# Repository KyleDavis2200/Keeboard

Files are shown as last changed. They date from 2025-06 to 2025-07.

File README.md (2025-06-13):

# Keeboard

In this project, I made a custom mechanical keyboard using a Raspberry Pi Pico clone. The main feature that makes this unique is the connectors on either side of the board that allow it to be connected to external modules. I plan to make a wireless macropad / numberpad in a future project, that can be connected to either side of the keyboard to charge. These connectors will also include I²C communication, which should give me the option of adding more features, such as a screen, in the future.



# Features

* Modular design allows for future expansions.
* Tenkeyless Layout
* 87 Keys
* 3D Printed Case and Plate
* 3D Printed TPU Feet
* USB C Connector
* KMK Firmware

# Background

My main inspiration when designing this keyboard came from the Mountain Everest Max. The Everest Max features a removable number pad which can be attached to either side of the keyboard. This allows you to put it on the left side, which is more convenient for daily usage as it allows you to type in numbers with your left hand and move the mouse with your right hand without stretching your hand too far over. This setup is also ideal for gaming as it helps to maximize the mamount of mouse room on the right side of the board. To replicate this functionality in my own board, I put magnetic pogo pins on the sides of the board that allow the macropad/numberpad to connect to the keyboard. The four pins include a 5V pin, a ground pin, and two pins for I²C communication. This should leave me with plenty of options for expandability in the future.

The keyboard itself runs off of a Pi Pico clone, which was chosen for its high quanitity of GPIO pins and USB C port (compared to the Micro USB B port of the actual Pico). It uses MMD Princess V2 Tactile Switches, and its keys are arranged in a 6x17 matrix. The keyboard has a white color scheme with Blue 8008 keycaps. The case and plate are designed to be printed in two halves and then assembled, where they will then be held to gether by keying features, heat set inserts, and the screws running through the case and PCB. The case also features carefully placed cylinders to act like standoffs to support the PCB. The aim with this was to give the board a more solid feel than it otherwise would have, as I was worried about the PCB flexing if a key is pressed too hard.

# Images

### PCB:

Schematic:



Front:



Back:



3D View:



### CAD:

Isometric:



Front View:



Side View:



Top View:



Back View:



# BOM

| Item | Price  | Link |
| --- | --- | --- |
| RP2040 Pico USB C | 1.99 | https://www.aliexpress.us/item/3256808040042288.html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"order"%3A"30"%2C"eval"%3A"1"%7D&pdp_npi=4%40dis%21USD%2110.51%213.69%21%21%2175.16%2126.43%21%40210337c117496162516362210eb7d4%2112000044297086886%21sea%21US%216330817038%21X&curPageLogUid=oRgrVCWBuHse&utparam-url=scene%3Asearch%7Cquery_from%3A |
| Switches x110 | 23.6 | https://www.amazon.com/KPREPUBLIC-Princess-Tactile-Mechanical-Keyboard/dp/B0C533CCXY?th=1 |
| Key Caps | 29.99  | https://www.amazon.com/Sumgsn-Spacebar-Switches-Mechanical-Keyboard/dp/B0BNN2M9QD/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 |
| Stabilizers | 5.54 | https://www.aliexpress.us/item/3256801499984864.html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"order"%3A"111"%2C"eval"%3A"1"%7D&pdp_npi=4%40dis%21USD%215.54%215.54%21%21%215.54%215.54%21%40210318e817496929936517433e29c3%2112000017133740376%21sea%21US%216330817038%21X&curPageLogUid=4ANDMTxK2PfM&utparam-url=scene%3Asearch%7Cquery_from%3A |
| Cable | 2.59 | https://www.amazon.com/FEMORO-Monitor-Display-Transfer-Thunderbolt/dp/B0F23ZT4LV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 |
| PCB | 73.05  | JLC PCB |
| Diodes | 1.39 | idk how to link it since its in dollar express |
| Right Angle Pogo Pins | 6.04 | https://www.aliexpress.us/item/3256807268443322.html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 |
| Schottky Diode | 4.65 | https://www.aliexpress.us/item/3256803563924504.html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 |
| 8x M3 Heat Set Insert | N/A | Already have |
| 4x M3 x 20mm Screw | N/A | Already have |
| 4x M3 x 12mm Screw | N/A | Already have |
| PLA Filament | N/A | Already have |
| TPU Filament | N/A | Already have |
| Total: | 148.84 | |

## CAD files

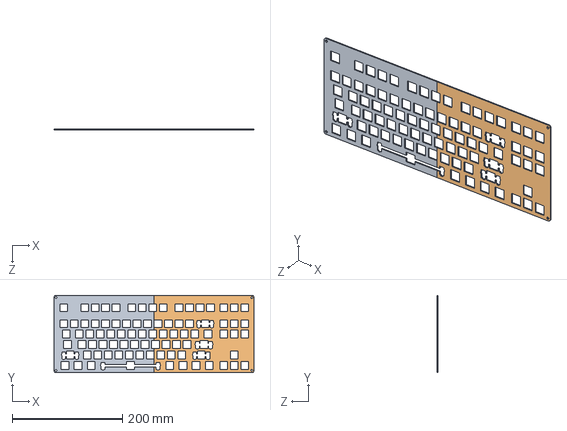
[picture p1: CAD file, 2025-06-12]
Plate STEP.STEP
363.1 x 139.9 x 1.50 mm

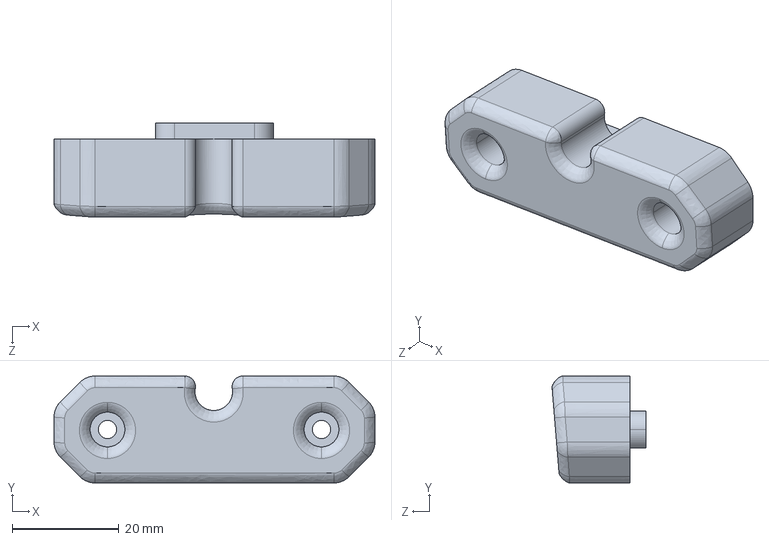
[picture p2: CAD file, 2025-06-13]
CAD/Top Left Foot.STEP
60.0 x 20.0 x 17.6 mm

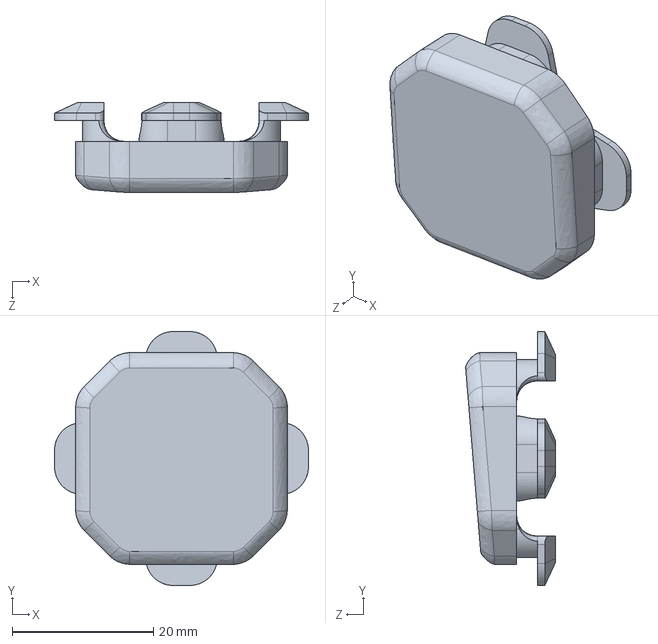
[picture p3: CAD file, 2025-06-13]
CAD/Lower Feet.STEP
36.0 x 36.0 x 12.7 mm

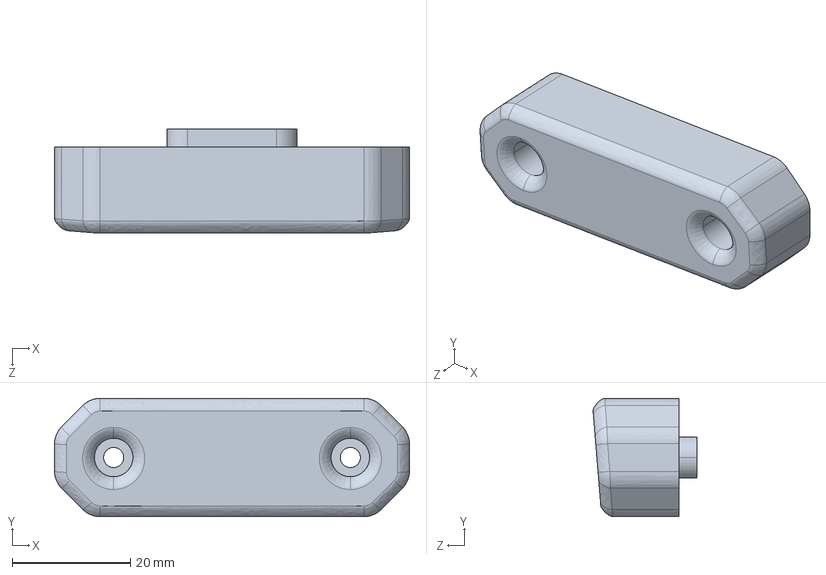
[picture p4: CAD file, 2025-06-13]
CAD/Top Right Foot.STEP
60.0 x 20.0 x 17.6 mm

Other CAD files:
CAD/Case.STEP
CAD/Plate.STEP

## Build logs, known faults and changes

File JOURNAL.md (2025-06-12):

---
title: KeeBoard
author: Kyle Davis
description: A custom keyboard designed with future expandability in mind
created_at: 2025-05-25
---

Total Time: 32 Hours

5/25/2025

4 Hours

I began this project by first researching how keyboard PCBs were laid out, as I knew that would be the main challenge in this project. I came across [a video series by Joe Scotto](https://www.youtube.com/playlist?list=PLBD2IS_t_iWZDMdG_ZF57x9Ebm3kxKqxF) that helped me understand exactly how everything would be laid out. These tutorials guided me towards keyboard-layout-editor.com, where I layed out a standard TKL layout for this keyboard.

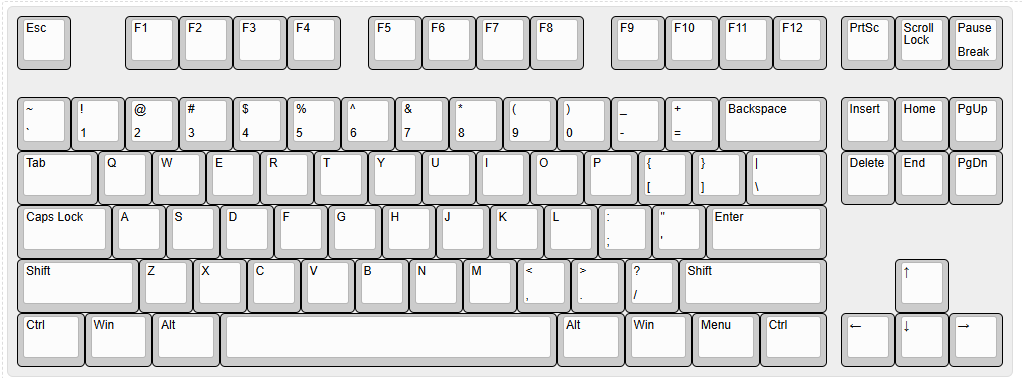
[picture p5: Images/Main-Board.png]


Following the instructions in these tutorials, I then began to plan out how I would layout the columns and rows for this keyboard. 
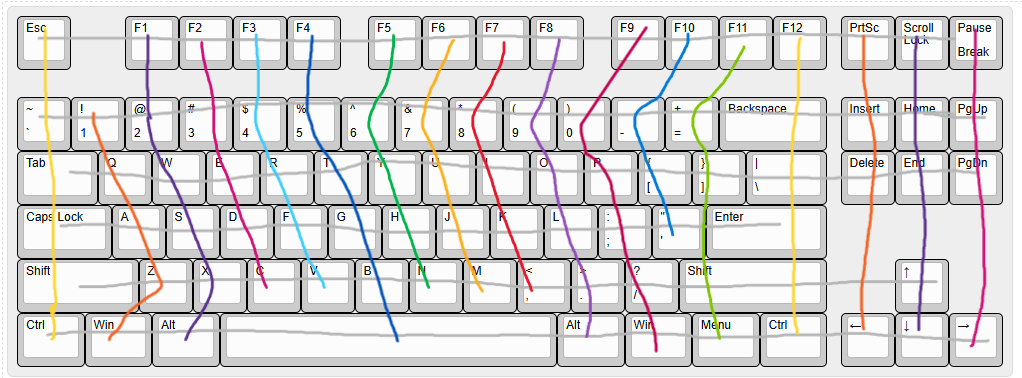
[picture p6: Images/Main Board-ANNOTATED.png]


5/26/2025

8 Hours

Using the previous drawing of the rows and columns for the key matrix, I began making a schematic in KiCad of the keyboard, using symbols from [Joe Scotto's library](https://github.com/joe-scotto/scottokeebs).

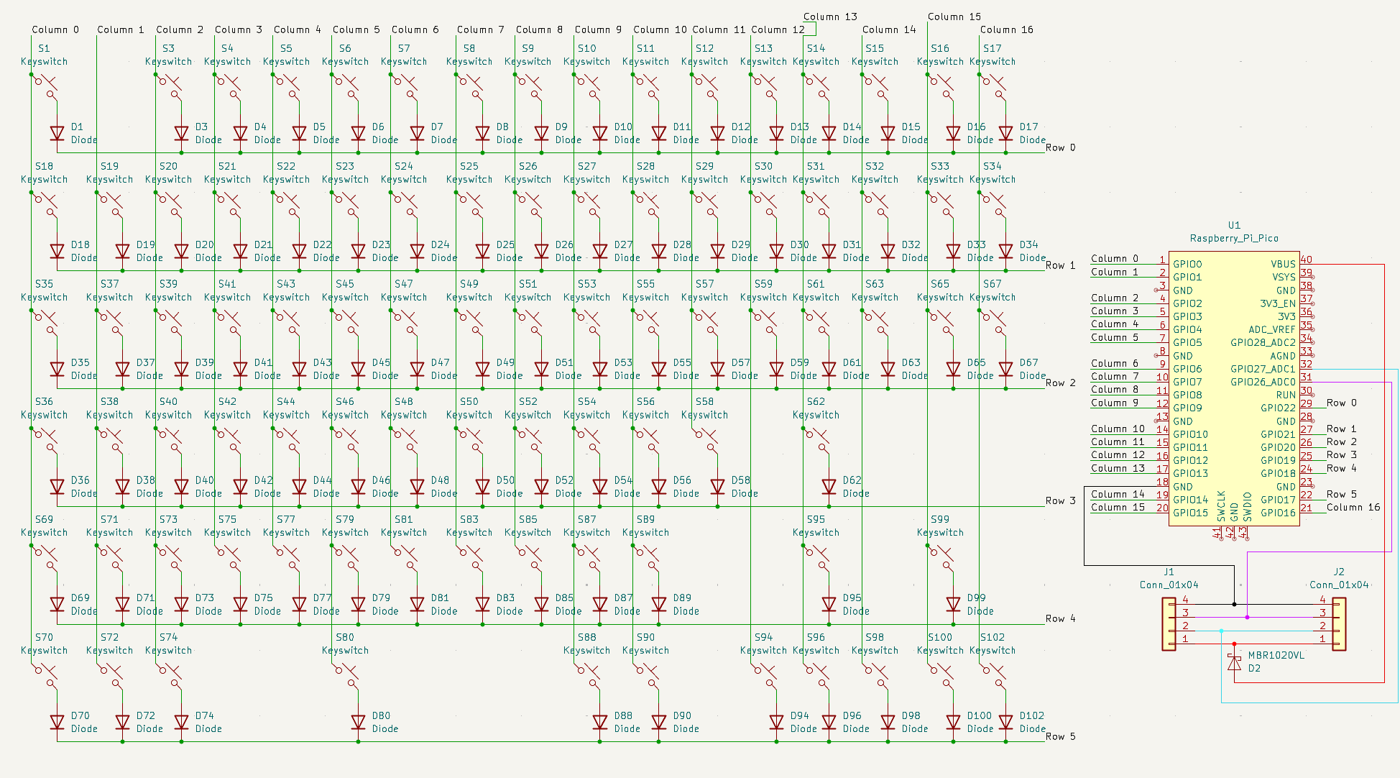
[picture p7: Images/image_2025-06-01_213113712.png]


I then moved onto selecting exactly which switches and keycaps I would use. I opted for Princess Tactile switches and 8008 keycaps. I also selected the cable and stabilizers I would be using for this build at this time.



Next, I created a rough layout of the PCB, including the Pico, the diodes, and all of the key switches.



5/30/25

2 Hours

Today, I polished up the board layout by adjusting the location of the Pico to better fit between the switches and made some of the remaining traces that I had not made previously. At this point, the remaining steps in the PCB design in Kicad are to add the connectors for expanding with future modules, adding a ground plane, and creating mounting for the stabilizers. After that, the rest of the design, designing the case and plate, will be done in Solidworks.

6/1/25

1 Hour

Today, I focused on getting the journal up to date and adding images to the journal. I also went back and switched from 3 pin connectors (which I had only been using 2 pins on, as I could not find 2 pin connectors) for the expandable modules to 4 pin connectors, which allowed me to use I²C to communicate with the external modules. This would allow me to use wired communication to the external modules, instead of just using the connection as a charging port for wireless modules. I do still aim to make a wireless macropad/keypad, but this creates the option of making a screen module or a slider/knob module. As of writing this, I am realizing that the signals for the I²C communication should be sent to seperate GPIO pins from the connector on each side of the keyboard, instead of sharing GPIO pins, which would make it possible to use two modules at a time. After some research, I found that I can connect the devices in parallel as I had previously designed them, which is ideal as I would have been one GPIO pin too short to make seperate a seperate I²C channel for each side of the board.

6/4/25

4 Hours

Today, I worked on getting the connectors for the external modules added to the PCB. I modeled each connector in Solidworks and then creasted a footprint for the connector with the 3D model in Kicad.




After this, I created the ground planes to finish the board layout and exported the board as a STEP file.

6/5/25

1 Hour

I imported the board into Solidworks and modeled the baseplate.

6/9/25

4 Hours

Today, I imported all of the keycaps into the model and modeled the plate. To create the cutouts for each key in the plate I used https://www.keyboard-layout-editor.com to make the layout and http://builder.swillkb.com to create a DXF profile where all of the cutouts for the keys would be. Then, I imported this to Solidworks as a DxF which I then used to create the cutouts in the plate.


6/10/25

6 Hours

All I had left to do today is design the case. I needed to design the case to split in half to fit on my printer. The case will be printed out of PLA and the feet on the bottom of the board will be printed out of TPU. The two halves of the case are aligned with keying features and are held together with the four M3 screws that hold the entire keyboard together. Each of the upper feet are held on with two M3 screws and also have a keying feature for alignment, while the lower feet are held on with four snap fit joints.



Finished Product:







Well... It turns out I wasn't finished. The keyboard came out way over budget, so I will need to redesign it to cut costs. Instead of using an aluminum plate and an aluminum base plate, I am going to make them both out of PLA (base plate integrated into case). This should cut costs significantly, but that will have to wait for another day.


6/11/25

1 Hour

Remade the case to incorporate the base plate into the print. I used heat set inserts to replace the tapped holes in the aluminum baseplate. Also split the plate in half to allow it to fit on my printer. With this, the design is done and all I have left to do is to optimize the BOM to get it under budget and to fully ship the project.

The board looks pretty much identical to how it did in the "finished product" above.

6/12/2025

1 Hour

Shipped the project! (:



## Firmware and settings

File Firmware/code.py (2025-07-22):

print("Starting")

import board
import supervisor
import board
import digitalio
import storage
import usb_cdc
import usb_hid
from kmk.kmk_keyboard import KMKKeyboard
from kmk.keys import KC
from kmk.scanners import DiodeOrientation

keyboard = KMKKeyboard()

keyboard.col_pins= (board.GP0, board.GP1, board.GP2, board.GP3, board.GP4, board.GP5, board.GP6, board.GP7, board.GP8, board.GP9, board.GP10, board.GP11, board.GP12, board.GP13, board.GP14, board.GP15, board.GP16) #Cols
keyboard.row_pins = (board.GP22, board.GP21, board.GP20, board.GP19, board.GP18, board.GP17) #Rows
keyboard.diode_orientation = DiodeOrientation.COL2ROW

#Keymap
keyboard.keymap =[
    [
        KC.ESC, KC.NO, KC.F1, KC.F2, KC.F3, KC.F4, KC.F5, KC.F6, KC.F7, KC.F8, KC.F9, KC.F10, KC.F11, KC.F12, KC.PSCREEN, KC.SCROLLLOCK, KC.PAUSE,
        KC.GRAVE, KC.N1, KC.N2, KC.N3, KC.N4, KC.N5, KC.N6, KC.N7, KC.N8, KC.N9, KC.N0, KC.MINUS, KC.EQUAL, KC.BSPC, KC.INS, KC.HOME, KC.PGUP,
        KC.TAB, KC.Q, KC.W, KC.E, KC.R, KC.T, KC.Y, KC.U, KC.I, KC.O, KC.P, KC.LBRC, KC.RBRC, KC.BSLS, KC.DEL, KC.END, KC.PGDN,
        KC.CAPS, KC.A, KC.S, KC.D, KC.F, KC.G, KC.H, KC.J, KC.K, KC.L, KC.SCLN, KC.QUOT, KC.NO, KC.ENT, KC.NO, KC.NO, KC.NO,
        KC.LSFT, KC.Z, KC.X, KC.C, KC.V, KC.B, KC.N, KC.M, KC.COMM, KC.DOT, KC.SLSH, KC.NO, KC.RSHIFT, KC.NO, KC.NO, KC.UP, KC.NO,
        KC.LCTL, KC.LGUI, KC.LALT, KC.NO, KC.NO, KC.SPC, KC.NO, KC.NO, KC.NO, KC.RALT, KC.RGUI, KC.NO, KC.NO, KC.RCTRL, KC.LEFT, KC.DOWN, KC.RIGHT,
    ]
]

if __name__ == "__main__":
    keyboard.go()

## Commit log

2025-06-02 Rename Main Board-ANNOTATED.png to Images/Main Board-ANNOTATED.png
2025-06-02 Rename Main Board.png to Images/Main Board.png
2025-06-02 Rename Main Board.png to Main-Board.png
2025-06-12 Create CAD
2025-06-13 Update and rename Top Left Foot.STEP to CAD/Top Left Foot.STEP
    [Top Left Foot.STEP]
2025-06-13 Update and rename Top Right Foot.STEP to CAD/Top Right Foot.STEP
    [Top Right Foot.STEP]
2025-06-13 Update and rename Plate STEP.STEP to CAD/Plate.STEP
    [Plate.STEP]
2025-06-13 Update and rename Lower Feet.STEP to CAD/Lower Feet.STEP
    [Lower Feet.STEP]
